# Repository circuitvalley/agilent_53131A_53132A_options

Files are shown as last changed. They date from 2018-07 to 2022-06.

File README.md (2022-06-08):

# Open Source Agilent 53131A 53132A Ultra Stable Oven Time base option and 3Ghz Option. 
These Source file belog to project published on www.circuitvalley.com. 

#OCXO Option
https://www.circuitvalley.com/2018/07/agilent-53132a-53131a-ocxo-ultra-high-stability-oven-time-base-upgrade-option-open-source.html

#3Ghz Option
https://www.circuitvalley.com/2018/08/agilent-53132a-53131a-diy-open-source-3ghz-channel-option-030-board-hp.html

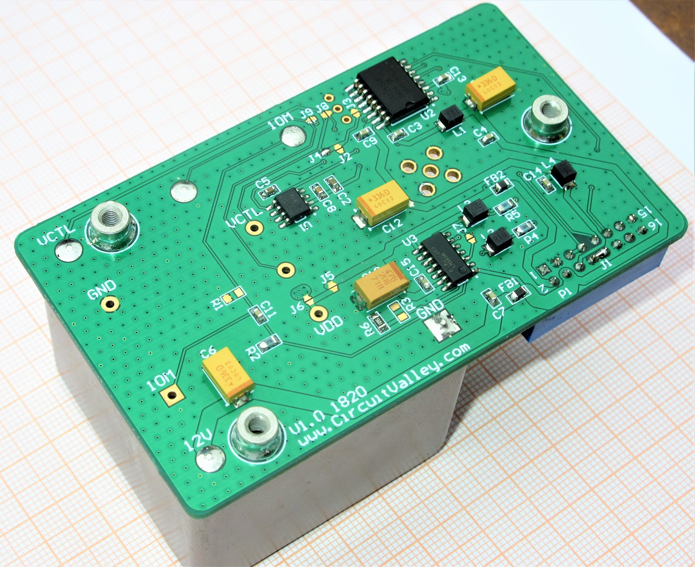
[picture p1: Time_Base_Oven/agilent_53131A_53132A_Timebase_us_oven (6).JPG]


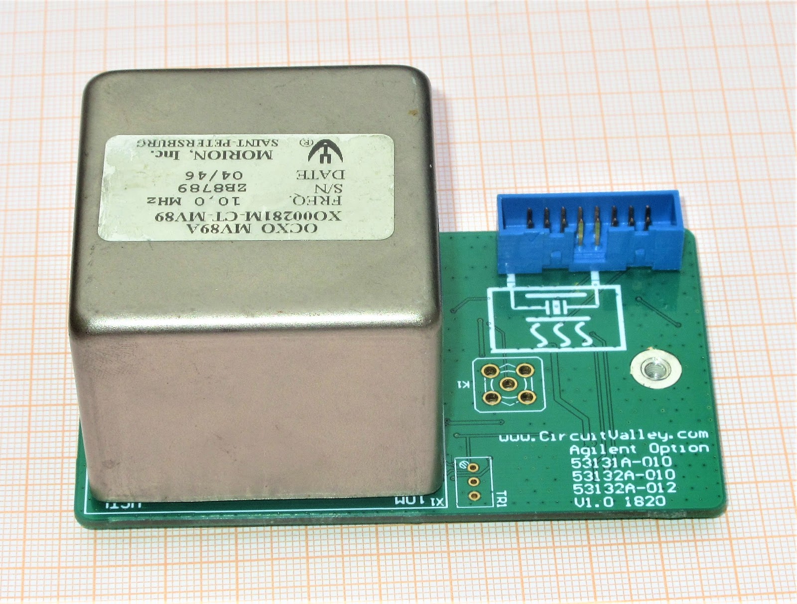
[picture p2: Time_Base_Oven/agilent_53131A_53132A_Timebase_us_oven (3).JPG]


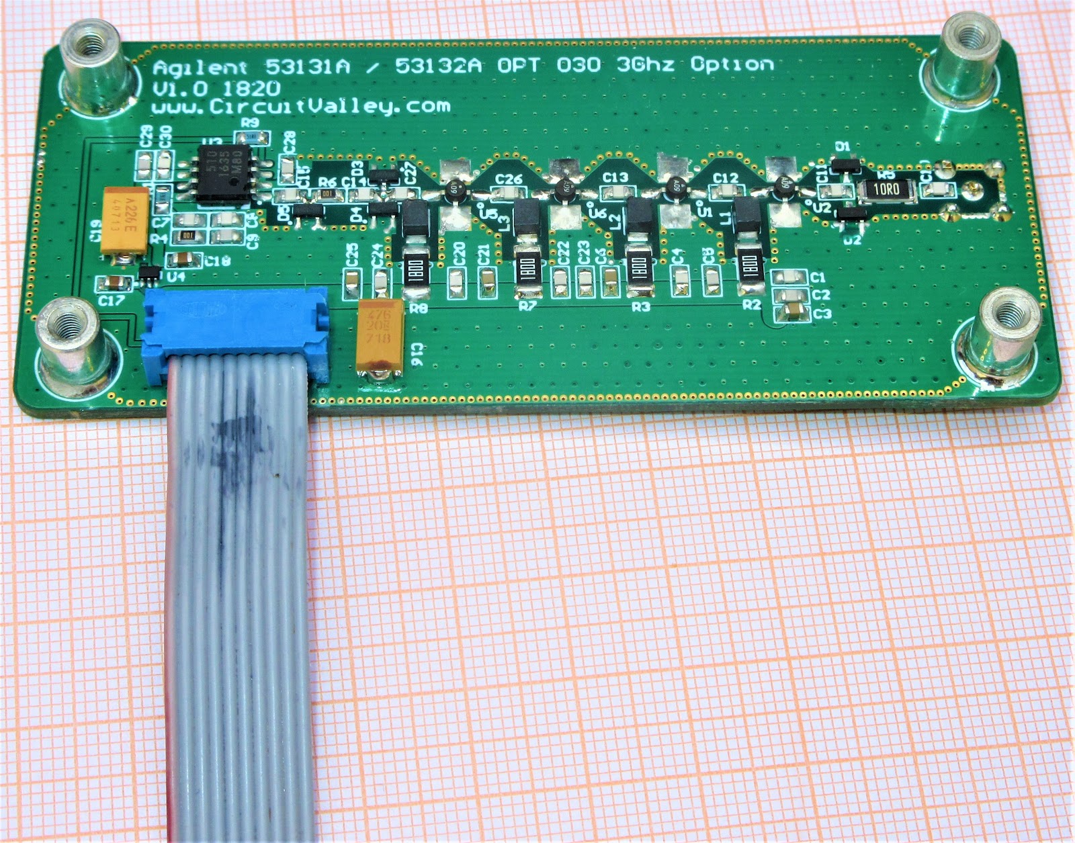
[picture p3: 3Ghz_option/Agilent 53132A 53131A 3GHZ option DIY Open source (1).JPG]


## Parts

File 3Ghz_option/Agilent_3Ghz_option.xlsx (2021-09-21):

Comment | Description | Designator | Footprint | Part | Quantity
56p | CAP Ceramic | C1, C4, C7, C8, C11, C12, C13, C15, C20, C23, C26, C30 | 0805C | CC0805FRNPO9BN560 | 12
1000p | CAP Ceramic | C2, C5, C9, C21, C24, C28, C29 | 0805C | GRM2165C1H102FA01J | 7
1u | CAP Ceramic | C3, C6, C18, C22, C25 | 0805C | VJ0805V105ZXJCW1BC | 5
220p | CAP Ceramic | C10, C14, C27 | 0805C | CC0805FRNPO9BN221 | 3
33uf 20V D | Cap Tantalum | C16, C19 | CAPMP7343X310N | TAJD336K020R | 2
100n | CAP Ceramic | C17 | 0805C | GRM21BR71H104KA01K | 1
HSMS-8202 | Schottky Barrier Double Diode | D1, D2, D3, D4, D5 | SOT23_N | HSMS-8202 | 5
Wurth Standoff | Wurth Standoff | DRL1, DRL2, DRL3, DRL4 | Wurth_PCB_STANDOFF_7740_6mm | 9774080360 | 4
NC | MCX Female PCB Mount Connector, Thru-Hole | J1 | CON-MCX | NC | 1
220n | Inductor | L1, L2, L3, L4 | NLV32T | NLV32T-R22J-EF | 4
IDC | IDC connector | P1 | HDR2X5 | 69830010LF | 1
10R | Resistor anti surge | R1,R6 | 0805R | ESR10EZPJ100 | 2
10R | Resistor anti surge | R5 | RESC5025N | CRS2010-FX-10R0ELF | 1
180R | Resistor SMD chip 1 Ohm 1W 1% 2010 | R2, R3, R7, R8 | RESC5025N | RC2010FK-07180RL | 4
316K | RESISTOR 0805 VALUE TO BE DETERMINED | R4 | 0805R | RK73H2ATTD3163F | 1
51.1R | RESISTOR 0805 VALUE TO BE DETERMINED | R9 | 0805R | RK73H2ATTE51R1F | 1
MSA-0986 | RF Gain Block | U1, U2, U5, U6 | SOT-86 | MSA-0986 | 4
MB510 | Prescaler | U3 | FPT-08P-M01 | MB510 | 1
MIC5213-5.0YC5 | LDO | U4 | SC70-5 | MIC5213-5.0YC5 | 1

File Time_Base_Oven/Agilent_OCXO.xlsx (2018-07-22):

Comment | Description | Designator | Footprint | Part Number | Quantity
22uf 20V D | Cap Tant | C1, C6, C12 | CAPMP7343X310N | TCJY226M025R0070, TCJY226M025R0070, T495D476K020ATE175, TCJY226M025R0070 | 3
47uf 20V D | Cap Tant | C10 | CAPMP7343X310N | T495D476K020ATE175 | 1
2.2u | Cap SMD Ceramic | C2, C5 | CAPC1608N | GRM188R6YA225KA12D | 2
100n | Cap SMD Ceramic | C3, C4, C7, C9, C11, C13, C14, C15 | CAPC1608N | C0603X104K5RAC | 8
10n | Cap SMD Ceramic | C8 | CAPC1608N | C0603X103K5RAC | 1
Weurth Standoff | Weurth Standoff | DRL1, DRL2, DRL3 | Wurth_PCB_STANDOFF_7740_6mm | 9774050360 | 3
Ferrite Bead | FERRITE BEAD 600 OHM 2A | FB1, FB2 | 0805FB | ILHB0805ER300V | 2
Solder Jumper | SOLDERDOT BYPASS | J1,J2, J3, J4, J5, J6, J7, J8, J9 | BYPASS-CLOSED |  | 9
SMA-V | SMA Connector | K1 | SMA-V | NC | 1
100u | Inductor | L1, L4 | NLV32T | NLCV32T-101K-EF | 2
100n | Inductor | L2 | NLV32T | NLV32T-R10J-EF | 1
1u | Inductor | L3 | NLV32T | NLCV32T-1R0M-EF | 1
IDC | IDC 8x2 | P1 | HDR2X8 | 75869303LF | 1
NC | RESISTOR 0805 | R1 | 0805R | NC | 1
215R | RESISTOR 0805 | R2 | 0805R | RK73H2ATTD2150F | 1
5K6 | RESISTOR 0805 | R3, R6 | 0805R | RC0805FR-075K6L | 2
100R | RESISTOR 0805 | R4, R5 | 0805R | RK73H2ATTE1000F | 2
Trimpot | TRIMMABLE RESISTOR | TR1 | TRIMMER-MT | T93XA103KT20 | 1
MAX6350CSA / ADR4550 / AD6250 | +5V Voltage Reference 1ppm/°C, Low-Noise, | U1 | NSO8_N | MAX6350CSA | 1
AD7243AR | DAC | U2 | SOIC-16_WIDE | AD7243AR | 1
LM361M | High Speed Differential Comparator | U3 | M14A_N | LM361M | 1
MV89A | OCXO | X1 | MV89A | MV89A | 1
OCXO 36x27 | OCXO | X2 | OCXO_Small | CTS 970 | 1

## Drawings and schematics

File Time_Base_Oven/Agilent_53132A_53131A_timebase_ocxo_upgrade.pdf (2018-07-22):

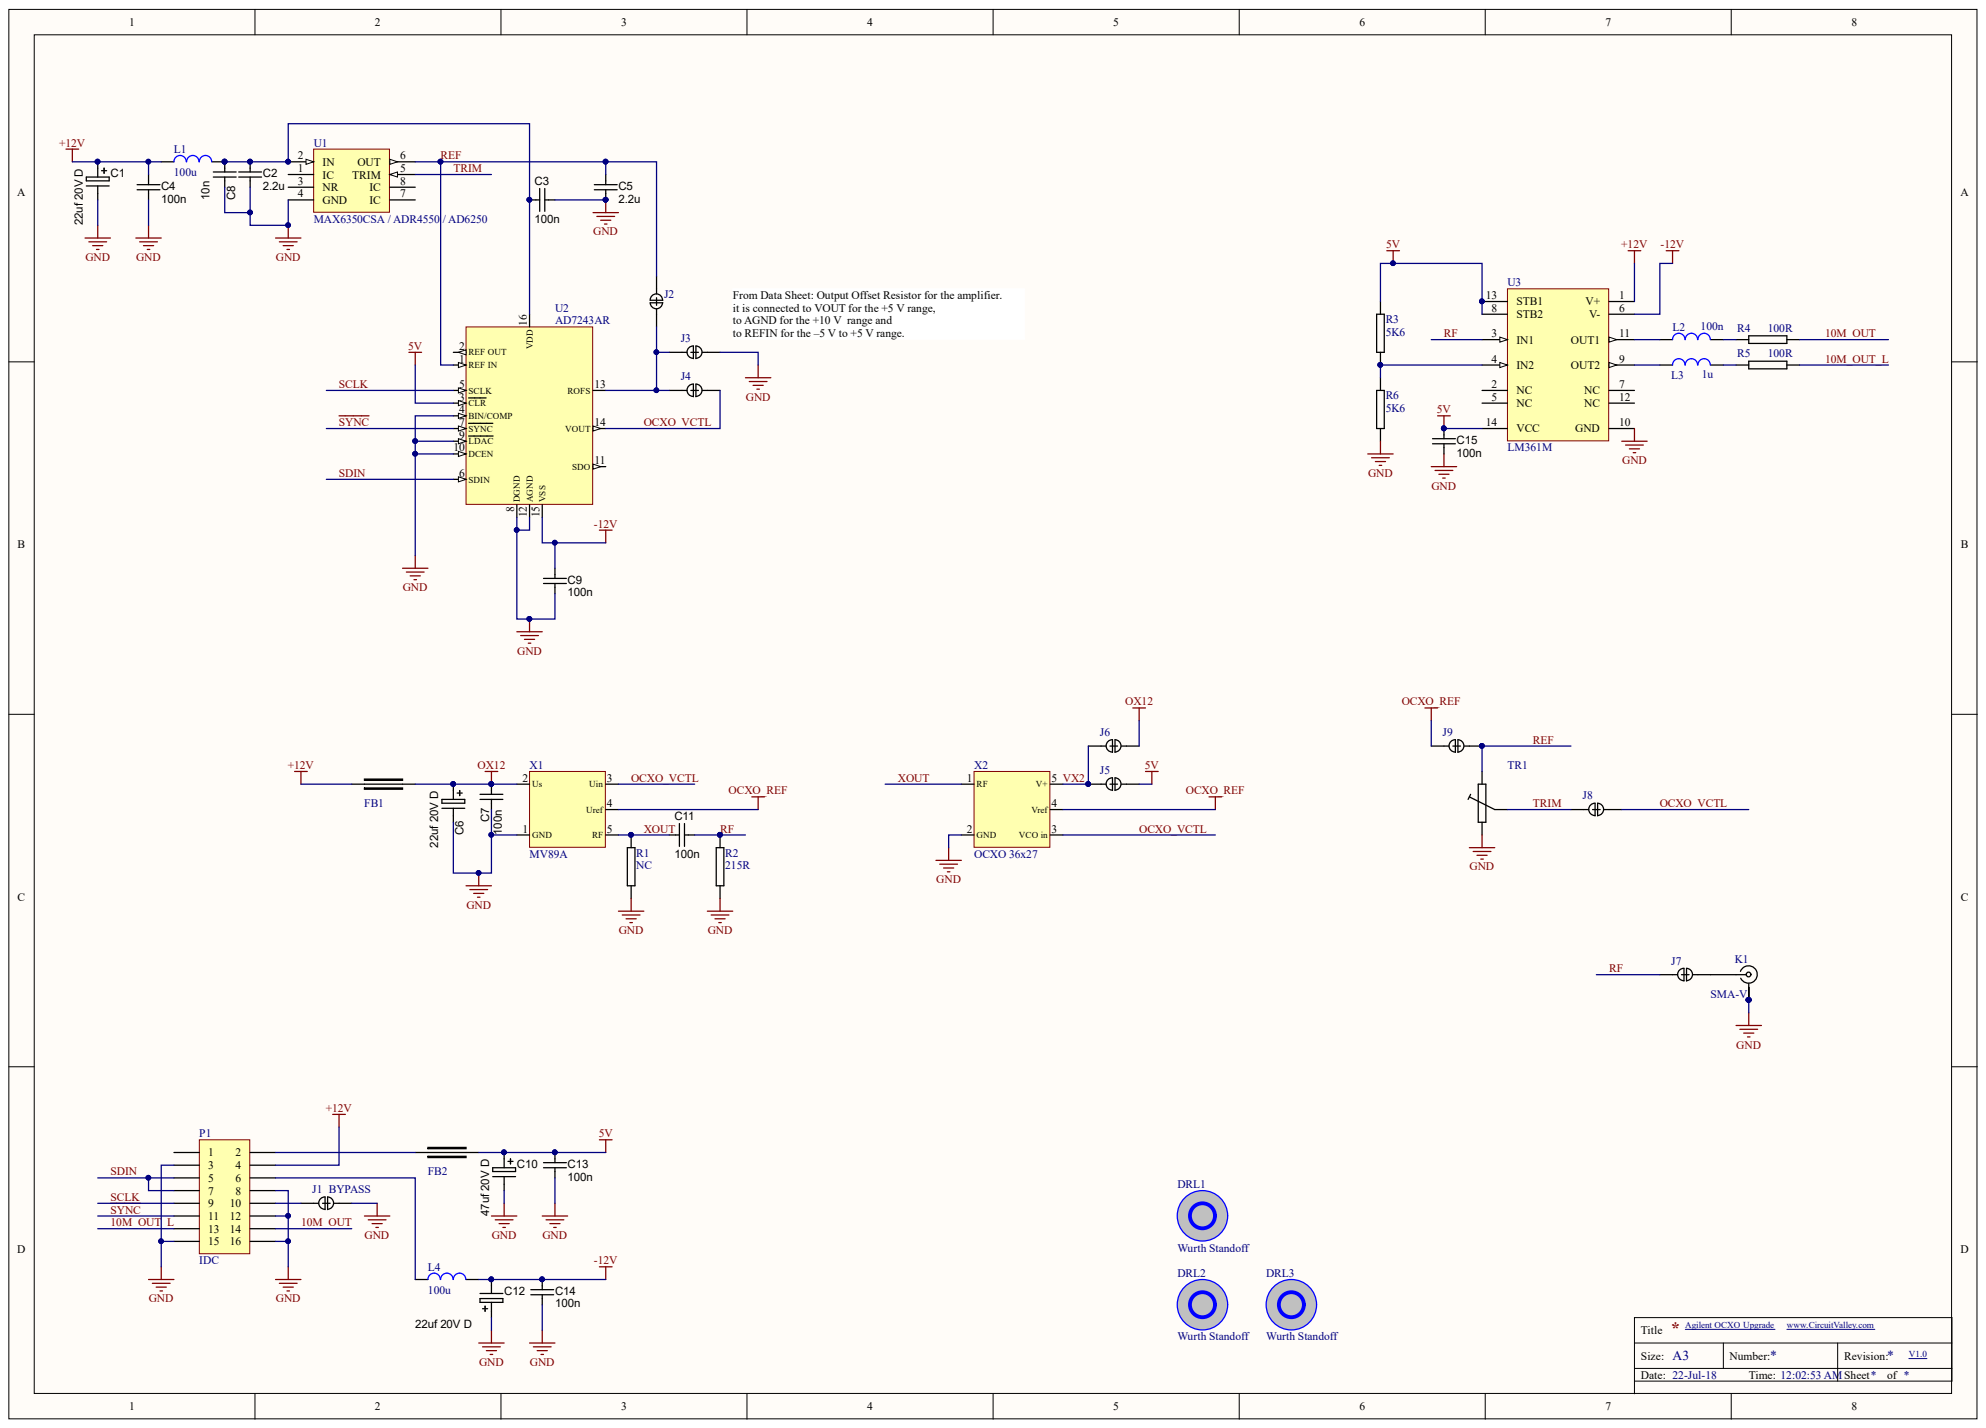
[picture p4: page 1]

From Data Sheet: Output Offset Resistor for the amplifier.
it is connected to VOUT for the +5 V range,
to AGND for the +10 V range and
to REFIN for the –5 V to +5 V range.

SYNC 7
LDAC 9
DCEN 10

Size: A3 | Number: * | Revision: * V1.0

Date: 22-Jul-18 Time: 12:02:53 AM | | Sheet * of *

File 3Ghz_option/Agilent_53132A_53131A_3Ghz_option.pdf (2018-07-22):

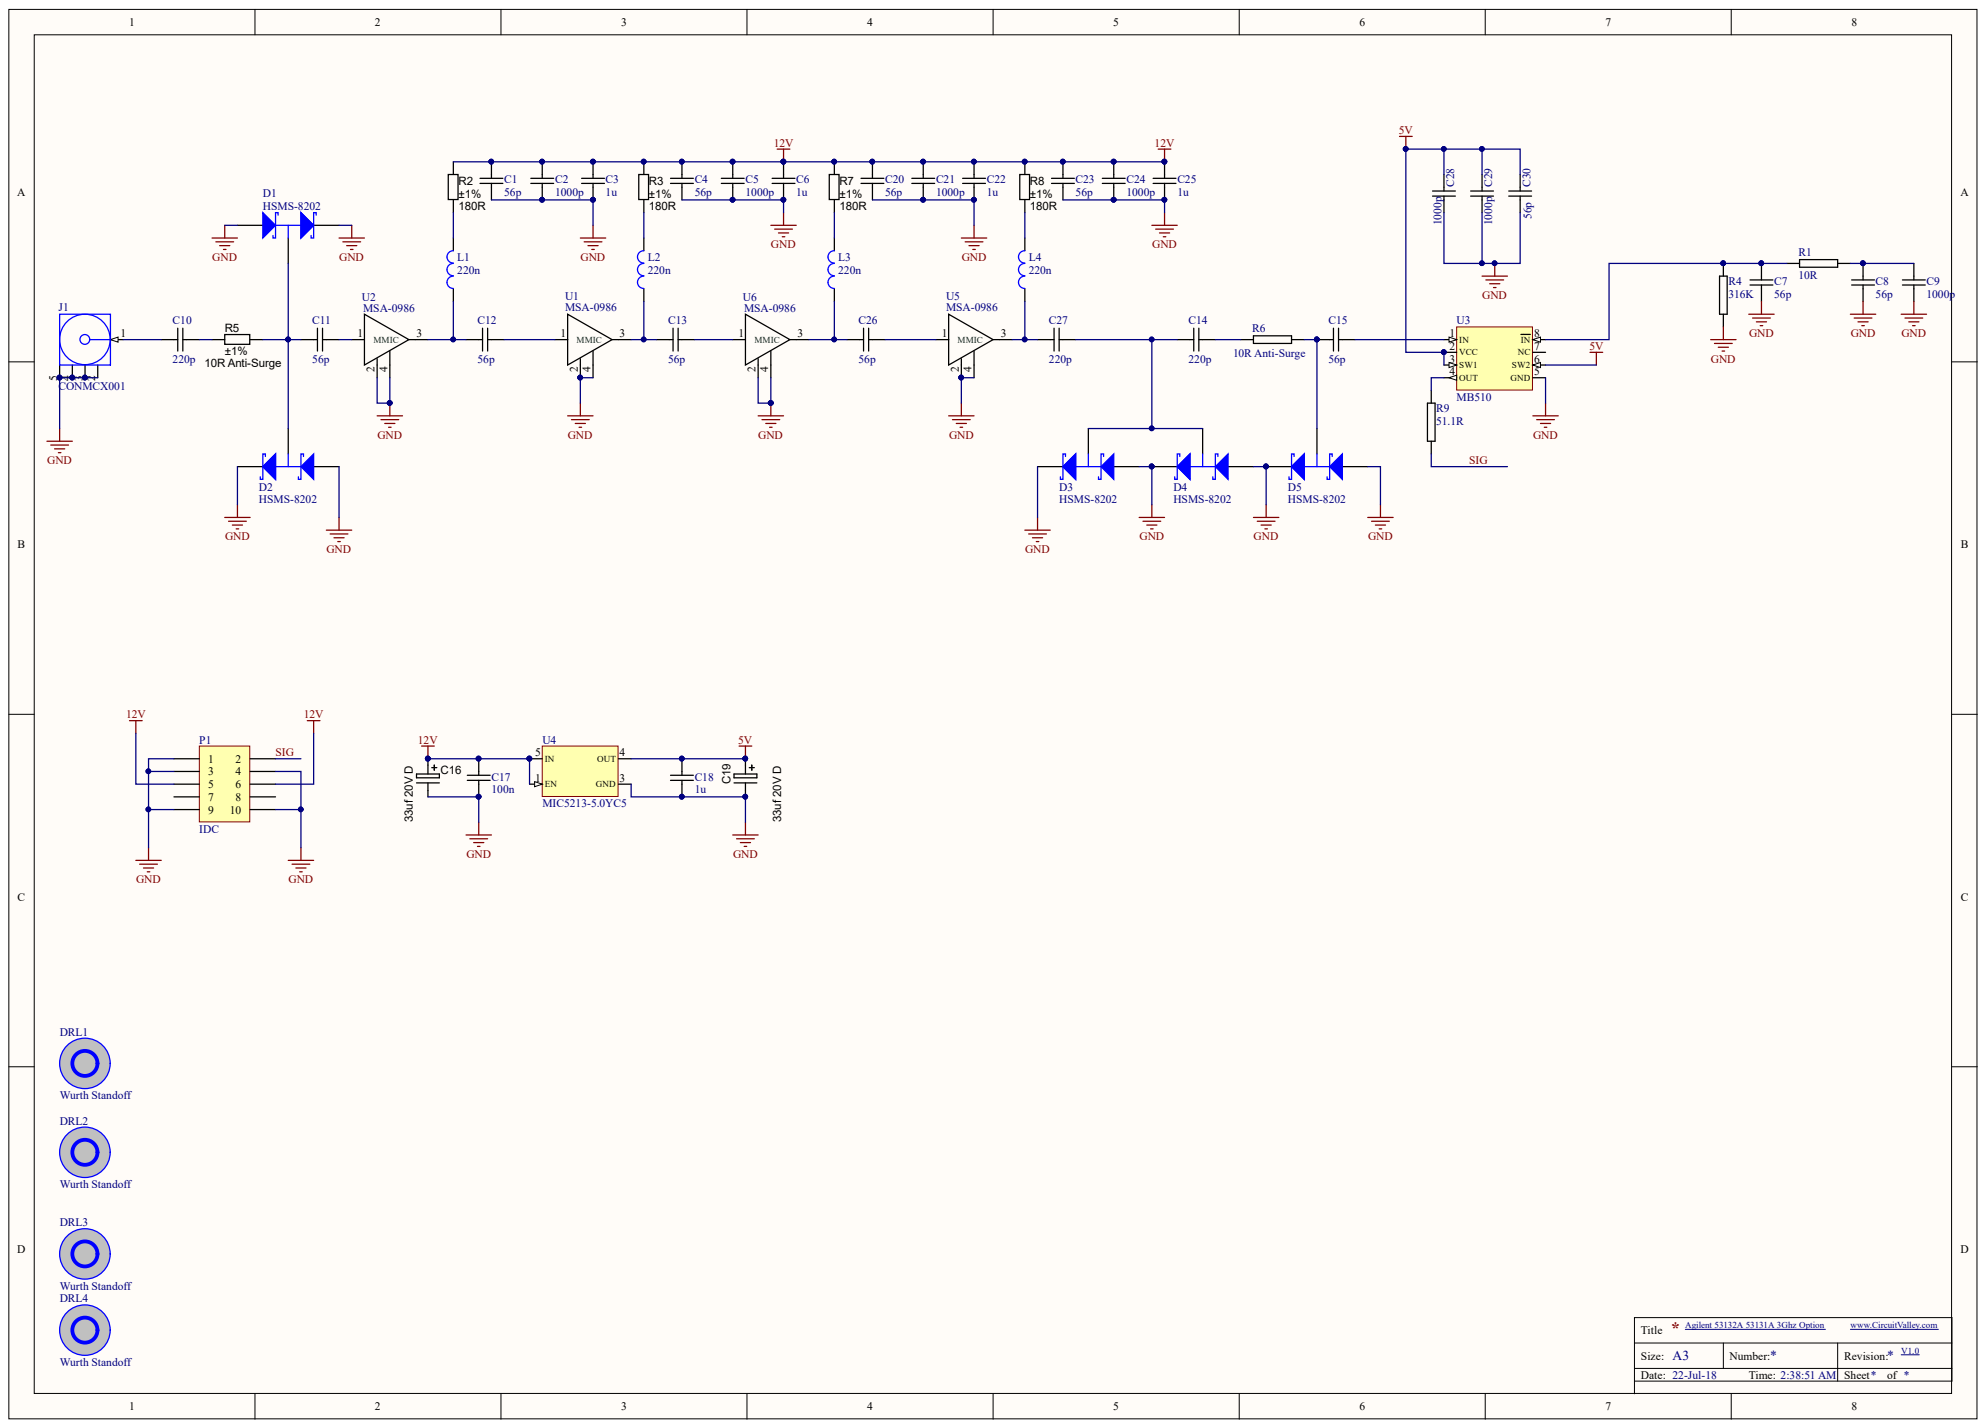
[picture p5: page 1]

Size: A3 | Number: * | V1.0 Revision: *

Date: 22-Jul-18 Time: 2:38:51 AM | | Sheet * of *

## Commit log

2018-07-22 Added time base PCB schematic gerber and source
    [Agilent_OCXO.SchDoc, Agilent_ocxo.PcbDoc]
2018-07-22 3Ghz option files added
    [Agilent_3Ghz_option.PcbDoc, Agilent_OCXO.SchDoc]
2018-07-22 added bill of material
    [Agilent_3Ghz_option.SchDoc, Agilent_3Ghz_option.xlsx, Agilent_OCXO.SchDoc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]
2020-02-02 fixed bom issue with R3
    [Agilent_3Ghz_option.xlsx]
2021-09-21 Fixed BOM for R1 and R3
    [Agilent_3Ghz_option.xlsx]
2022-06-08 Added board images
